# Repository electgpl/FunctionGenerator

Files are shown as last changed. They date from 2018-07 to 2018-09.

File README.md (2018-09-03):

# Generador de Funciones con XR2206 v1.0 

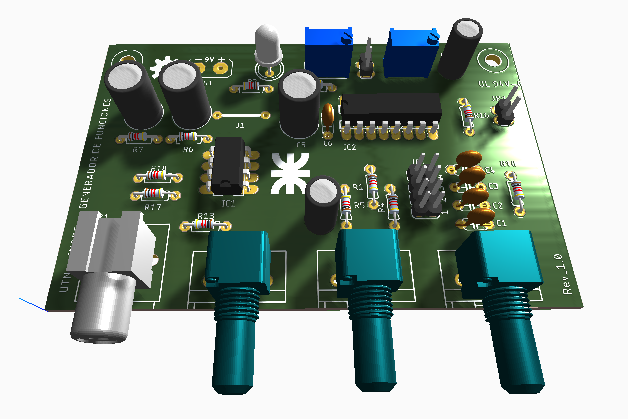
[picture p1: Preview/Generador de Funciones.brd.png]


# Generador de Funciones con XR2206 v2.0 

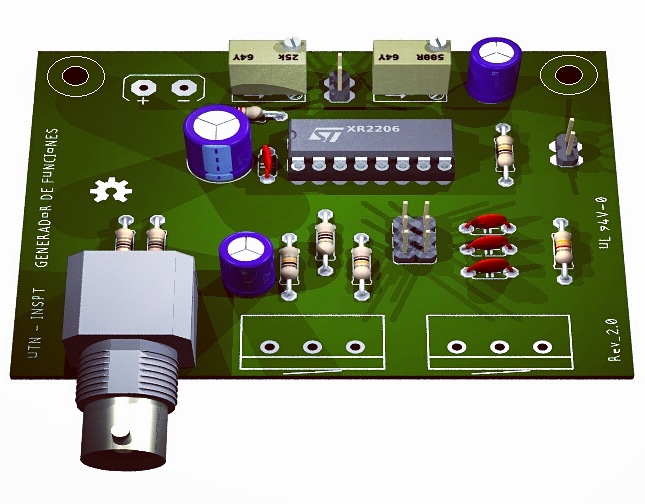
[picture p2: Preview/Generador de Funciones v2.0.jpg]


Este es un Generador de Señales discreto en base a componentes de fácil adquisición para facilitar la producción para ser ensamblado por los estudiantes.

## Controles - v1.0

  - Generador - **XR2206**
  - Preajuste de Simetría
  - Preajuste de Distorsión
  - Ajuste de Amplitud
  - Ajuste de Ganancia
  - Ajuste de Frecuencia
  - Selección de Rango de Frecuencia mediante Jumper o switch (4 rangos)
  - Selección de salida Triangular o Senoidal mediante Jumper o switch
  - Buffer de Salida
  - Salida BNC de 50R
  - Salida Cuadrada para Frecuencímetro y Sincronismo
  
## Controles - v2.0

  - Generador - **XR2206**
  - Preajuste de Simetría
  - Preajuste de Distorsión
  - Ajuste de Amplitud
  - ~~Ajuste de Ganancia~~
  - Ajuste de Frecuencia
  - Selección de Rango de Frecuencia mediante Jumper o switch ~~(4 rangos)~~ (3 rangos)
  - Selección de salida Triangular o Senoidal mediante Jumper o switch
  - ~~Buffer de Salida~~
  - Salida BNC de 50R
  - Salida Cuadrada para Frecuencímetro y Sincronismo

## Alimentacion

> Diseñado para ser alimentado con una única batería de 9V
> en su interior cuenta con una fuente con masa flotante para lograr la simetría en el amplificador operacional (solo para v1.0).
> El amplificador operacional puede ser reemplazado por cualquiera con entrada FET (Se requiere alta impedancia) (solo para v1.0).

### Diseño

> Diseñado con EAGLE, en solo una capa con componentes THT para facilitar
> la integración al alumno, el desarrollo del PCB en el hogar y mantener
> el menor costo posible.

### Pruebas de Señal Seno y Cuadrada

N|Solid

### Pruebas de FFT sobre Seno

N|Solid

Patrocinado
----
N|Solid (https://www.pcbway.es/)

License
----

MIT

**Free Software, Hell Yeah!**

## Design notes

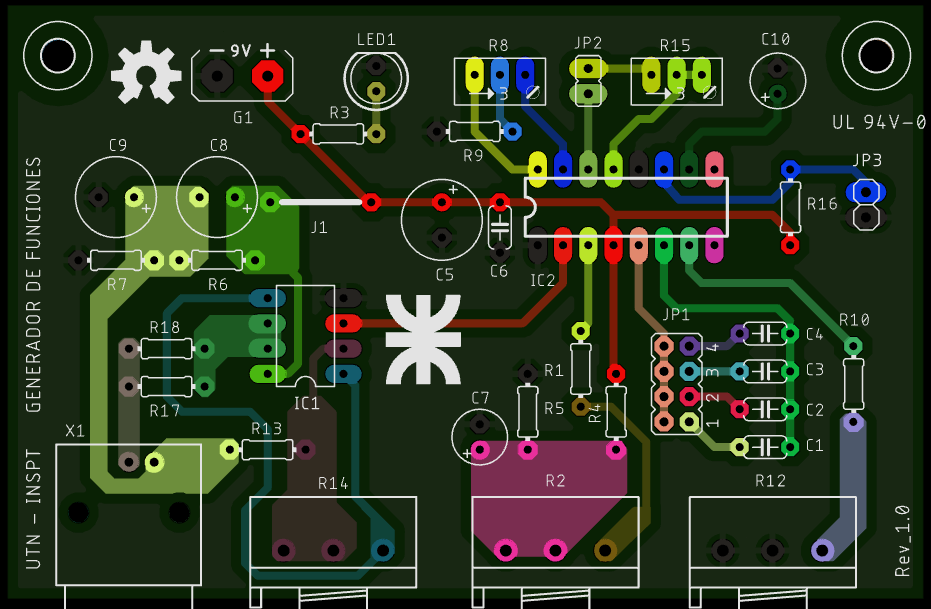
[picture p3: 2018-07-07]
Preview/Generador de Funciones Señales.png

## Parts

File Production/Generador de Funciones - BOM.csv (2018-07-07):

Qty | Value | Device | Package | Parts | Description | MF | MPN | OC_FARNELL | OC_NEWARK | SPICEPREFIX
1 |  | JP1Q | JP1 | JP2 | JUMPER
1 |  | JP4Q | JP4Q | JP1 | JUMPER
1 |  | LED5MM | LED5MM | LED1 | LED
1 |  | PINHD-1X2 | 1X02 | JP3 | PIN HEADER
1 | 1-227161-0 | 1-227161-0 | AMP_227161 | X1 | JACK, RIGHT ANGLE, 50 OHM, PCB, BNC | TYCO ELECTRONICS | 1-227161 | unknown | 33B3200
2 | 100 | R-US_0204/7 | 0204/7 | R17, R18 | RESISTOR, American symbol |  |  |  |  | R
1 | 100k | 3RP/1610N | 3RP/1610N | R12 | 16mm Potentiometer one level
2 | 100n | C-EU050-024X044 | C050-024X044 | C2, C6 | CAPACITOR, European symbol |  |  |  |  | C
1 | 10R | R-US_0204/7 | 0204/7 | R1 | RESISTOR, American symbol |  |  |  |  | R
1 | 10k | 3RP/1610N | 3RP/1610N | R2 | 16mm Potentiometer one level
4 | 10k | R-US_0204/7 | 0204/7 | R4, R5, R13, R16 | RESISTOR, American symbol |  |  |  |  | R
1 | 10n | C-EU050-024X044 | C050-024X044 | C3 | CAPACITOR, European symbol |  |  |  |  | C
1 | 10u | CPOL-EUE2.5-6 | E2,5-6 | C7 | POLARIZED CAPACITOR, European symbol |  |  |  |  | C
4 | 1k | R-US_0204/7 | 0204/7 | R3, R6, R7, R9 | RESISTOR, American symbol |  |  |  |  | R
1 | 1n | C-EU050-024X044 | C050-024X044 | C4 | CAPACITOR, European symbol |  |  |  |  | C
1 | 1u | C-EU050-024X044 | C050-024X044 | C1 | CAPACITOR, European symbol |  |  |  |  | C
1 | 1u | CPOL-EUE2.5-6 | E2,5-6 | C10 | POLARIZED CAPACITOR, European symbol |  |  |  |  | C
2 | 220u | CPOL-EUE3.5-8 | E3,5-8 | C8, C9 | POLARIZED CAPACITOR, European symbol |  |  |  |  | C
1 | 25k | 3RP/1610N | 3RP/1610N | R14 | 16mm Potentiometer one level
1 | 25k | TRIM_EU-RJ9W | RJ9W | R8 | POTENTIOMETER
1 | 3k3 | R-US_0204/7 | 0204/7 | R10 | RESISTOR, American symbol |  |  |  |  | R
1 | 470u | CPOL-EUE3.5-8 | E3,5-8 | C5 | POLARIZED CAPACITOR, European symbol |  |  |  |  | C
1 | 500R | TRIM_EU-RJ9W | RJ9W | R15 | POTENTIOMETER
1 | AB9V | AB9V | AB9V | G1 | 9-V BATTERY CLIP
1 | J10MM | J10MM | 10 | J1 | Bridge
1 | LM358N | LM358N | DIL08 | IC1 | OP AMP also LM158; LM258; LM2904
1 | OSHW-LOGOL | OSHW-LOGOL | OSHW-LOGO-L | U$4 | Open Source Hardware Logo This logo indicates the piece of hardware it is found on incorporates a OSHW license and/or adheres to the definition of open source hardware found here: http://freedomdefined.org/OSHW
1 | UTN_LOGO_0 | UTN_LOGO_0 | UTN_LOGO_0_TOP | U$1
1 | XR2206 | XR2206 | DIL16 | IC2 | XR2206 Monolithic Function Generator

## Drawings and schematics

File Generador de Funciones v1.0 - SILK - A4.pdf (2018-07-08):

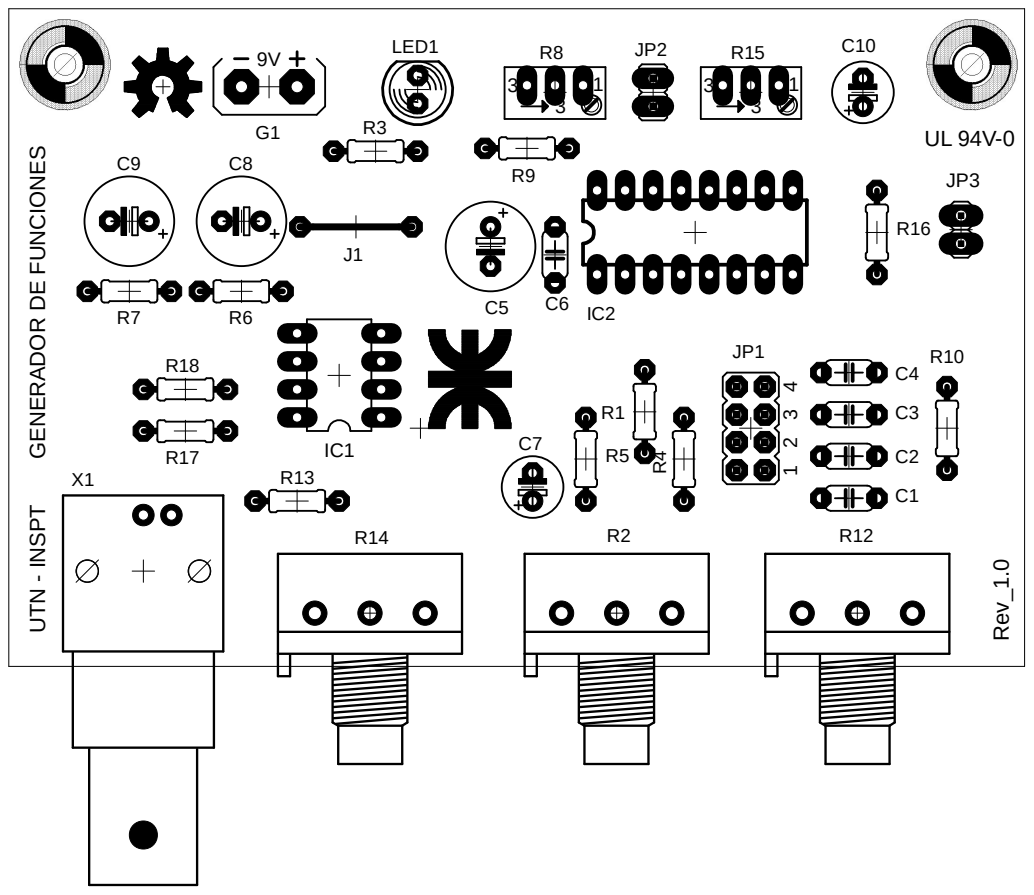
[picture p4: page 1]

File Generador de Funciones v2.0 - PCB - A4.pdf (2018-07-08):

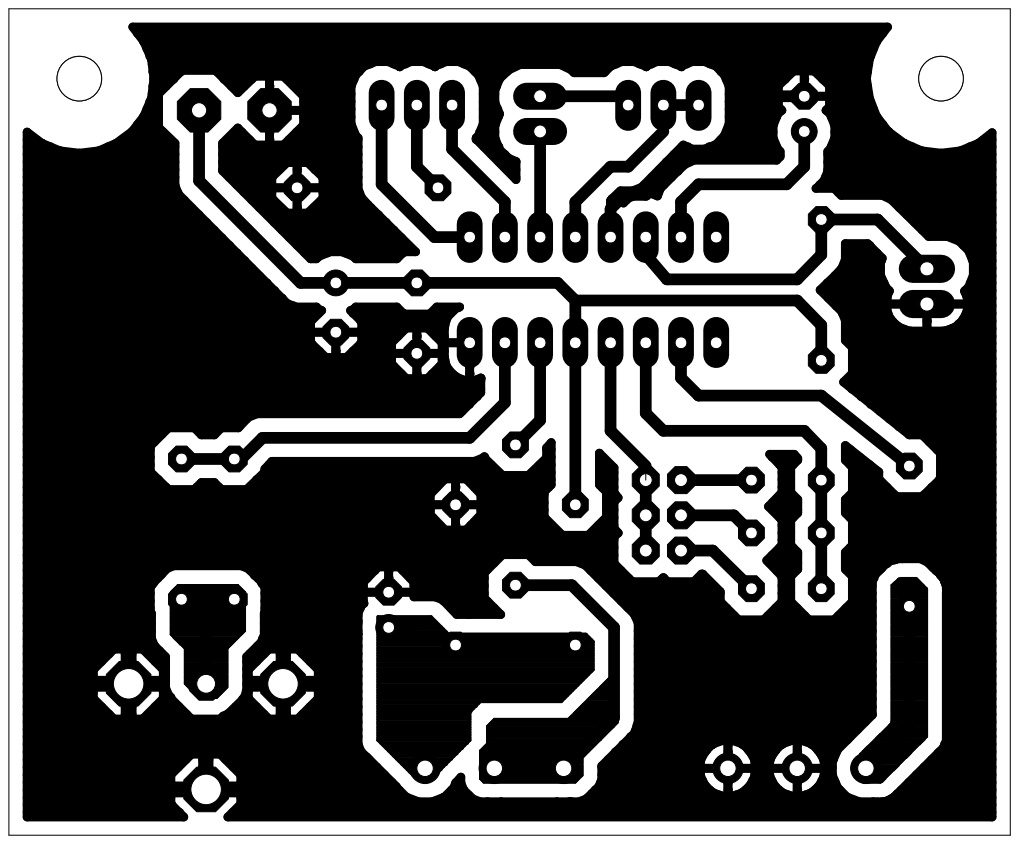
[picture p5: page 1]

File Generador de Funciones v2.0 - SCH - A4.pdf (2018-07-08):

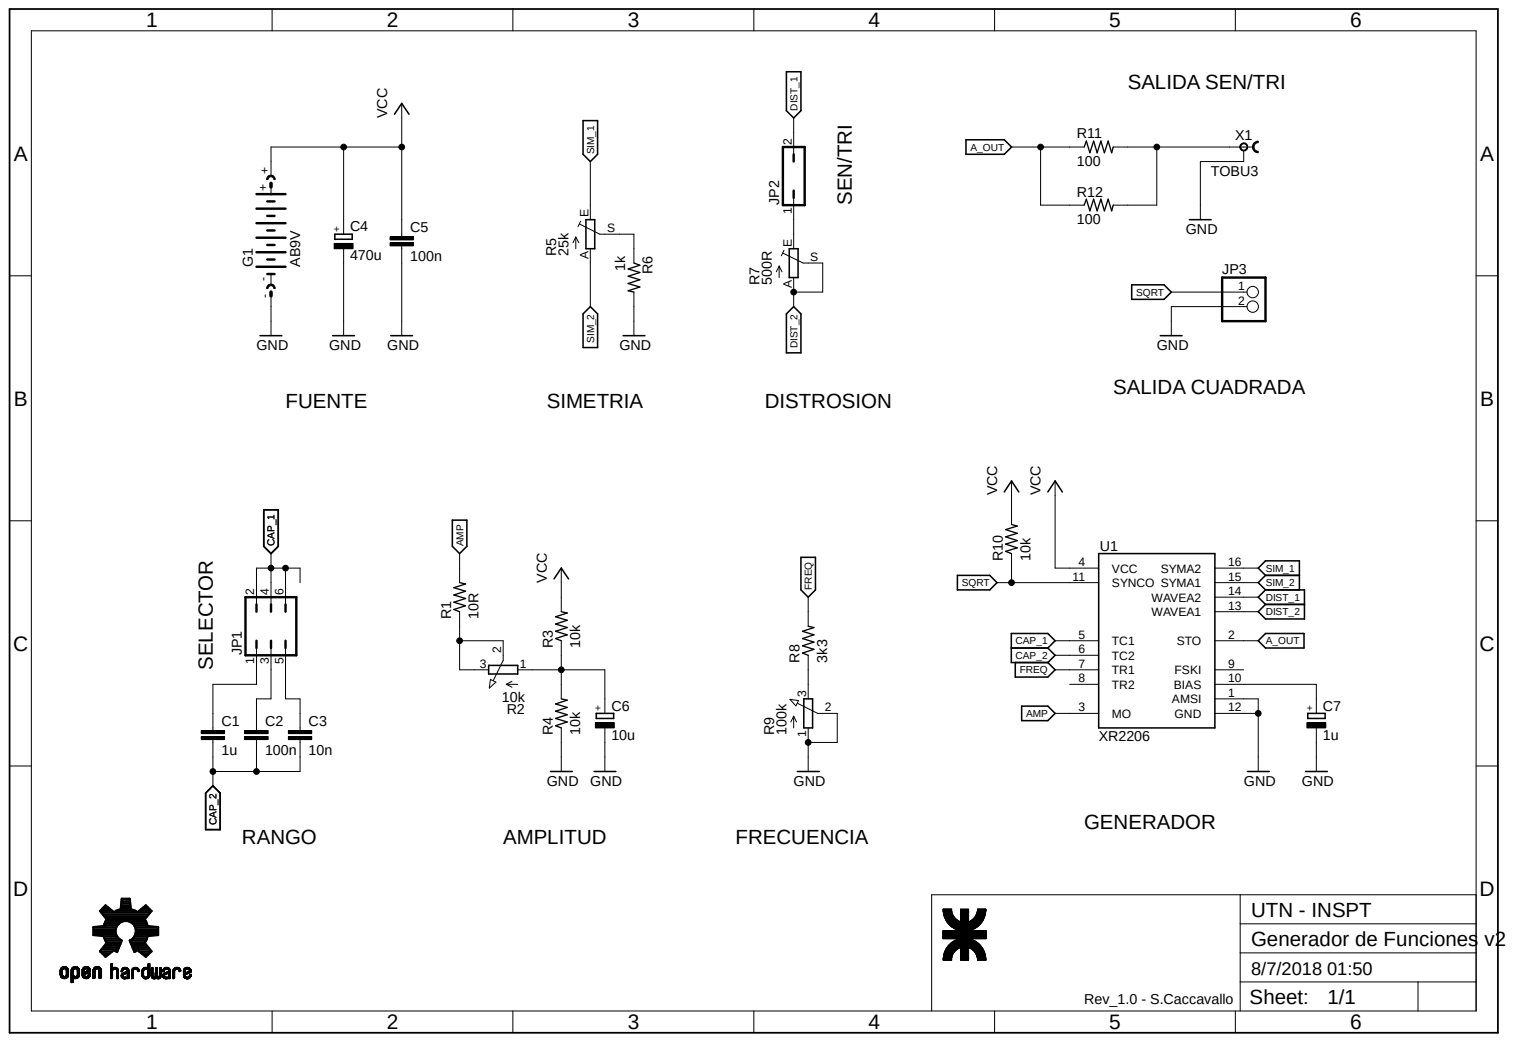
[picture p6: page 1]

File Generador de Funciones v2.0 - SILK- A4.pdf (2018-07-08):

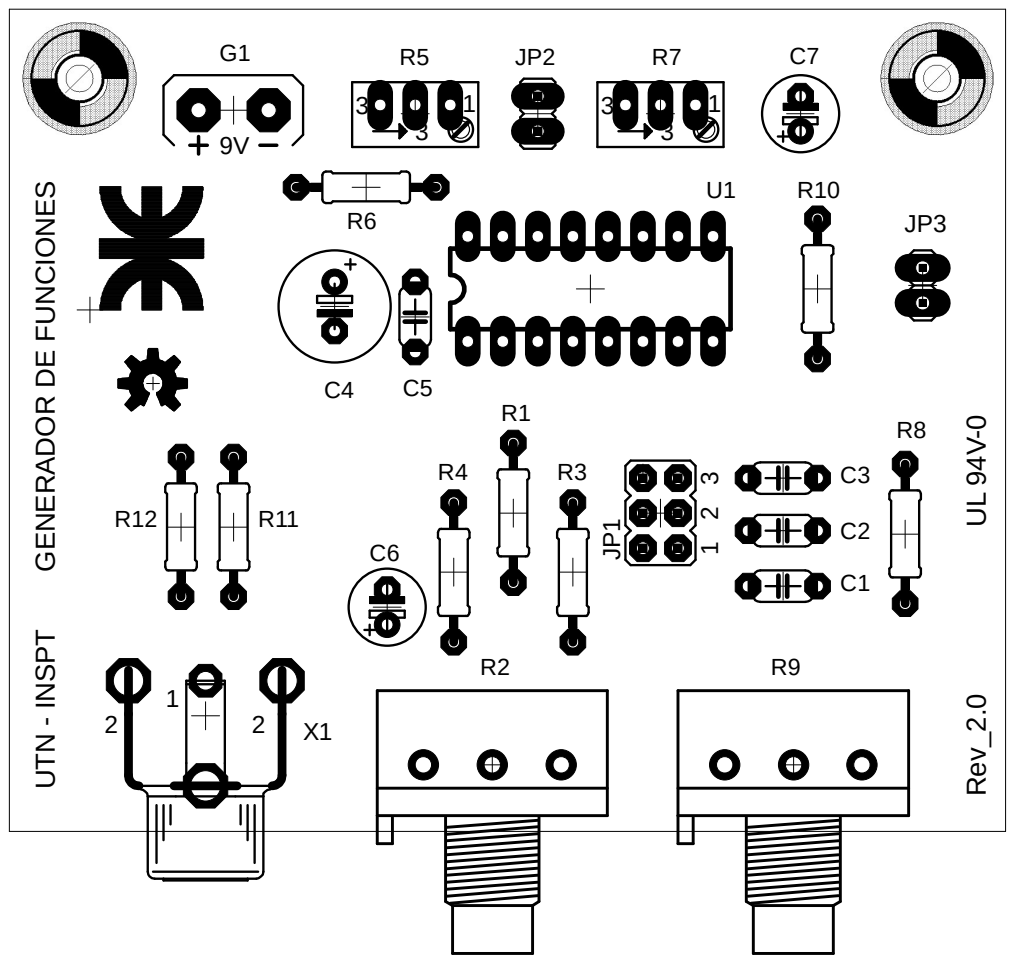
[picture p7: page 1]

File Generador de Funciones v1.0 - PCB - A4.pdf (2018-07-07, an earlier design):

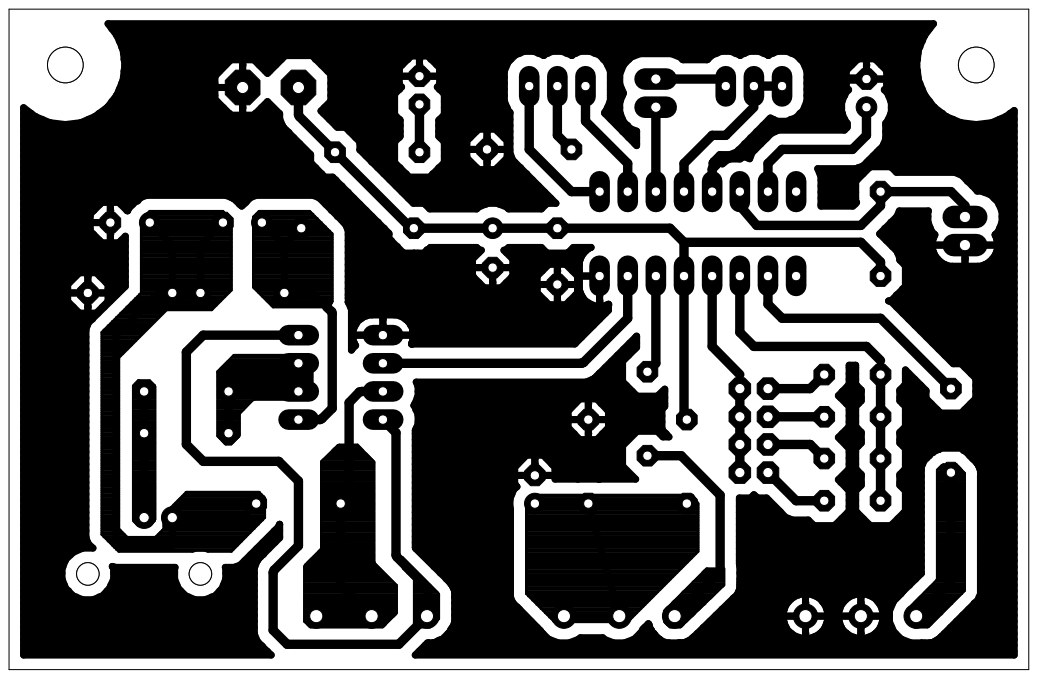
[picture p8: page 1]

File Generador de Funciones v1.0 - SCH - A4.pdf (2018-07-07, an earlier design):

## SALIDA SEN/TRI

A

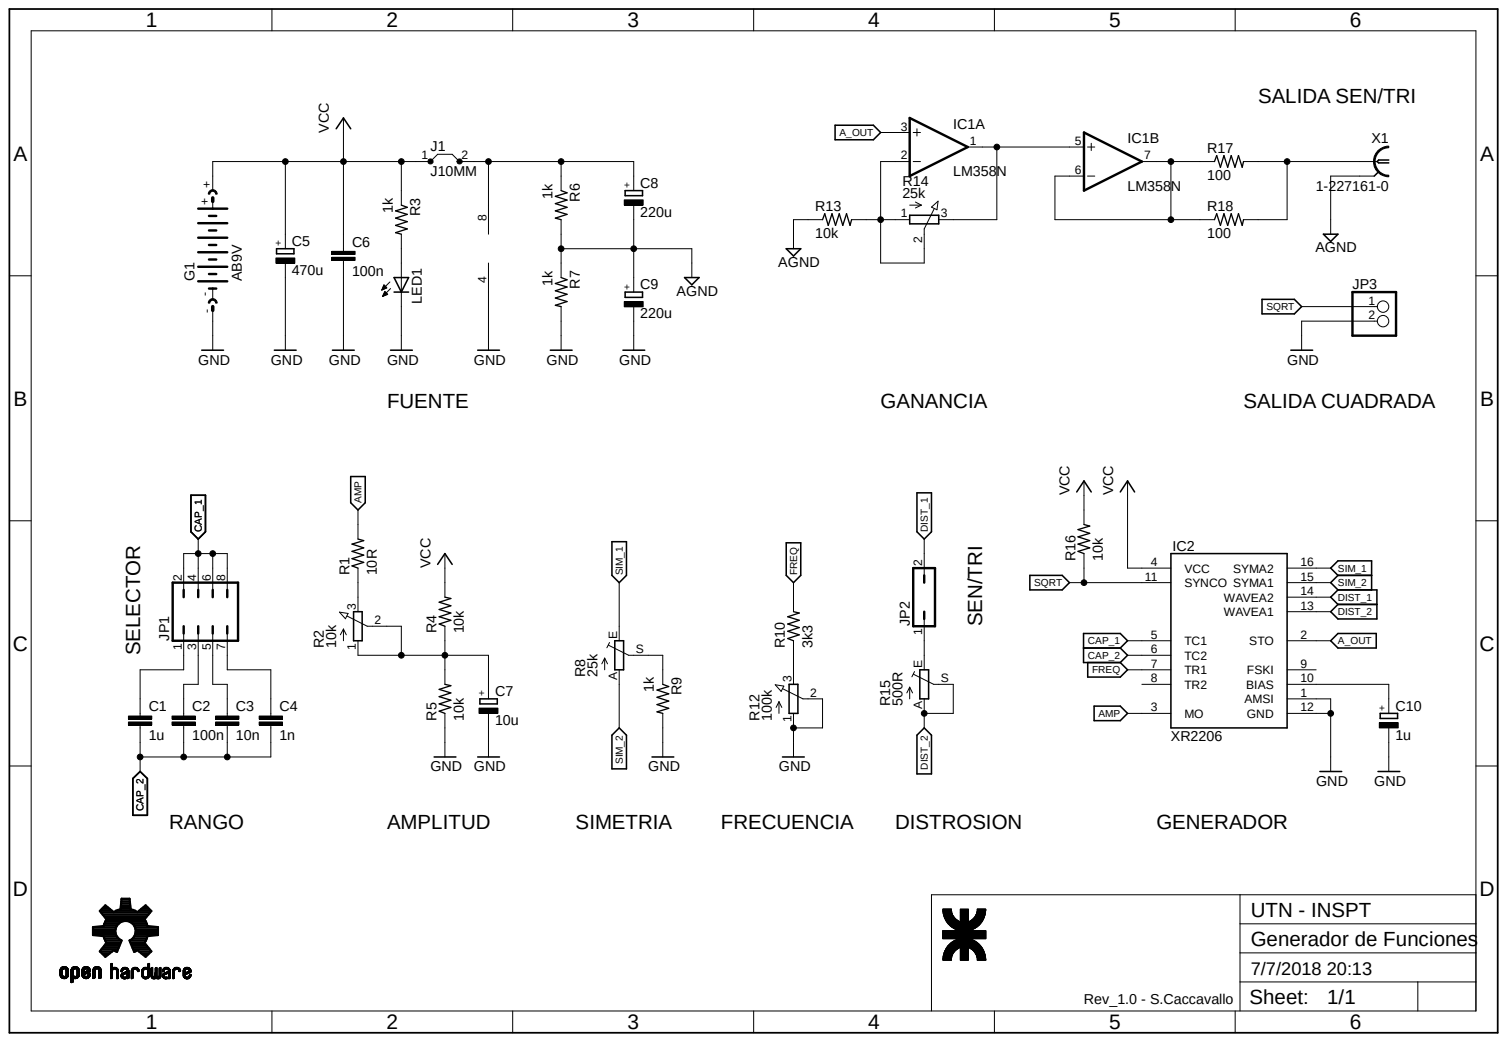
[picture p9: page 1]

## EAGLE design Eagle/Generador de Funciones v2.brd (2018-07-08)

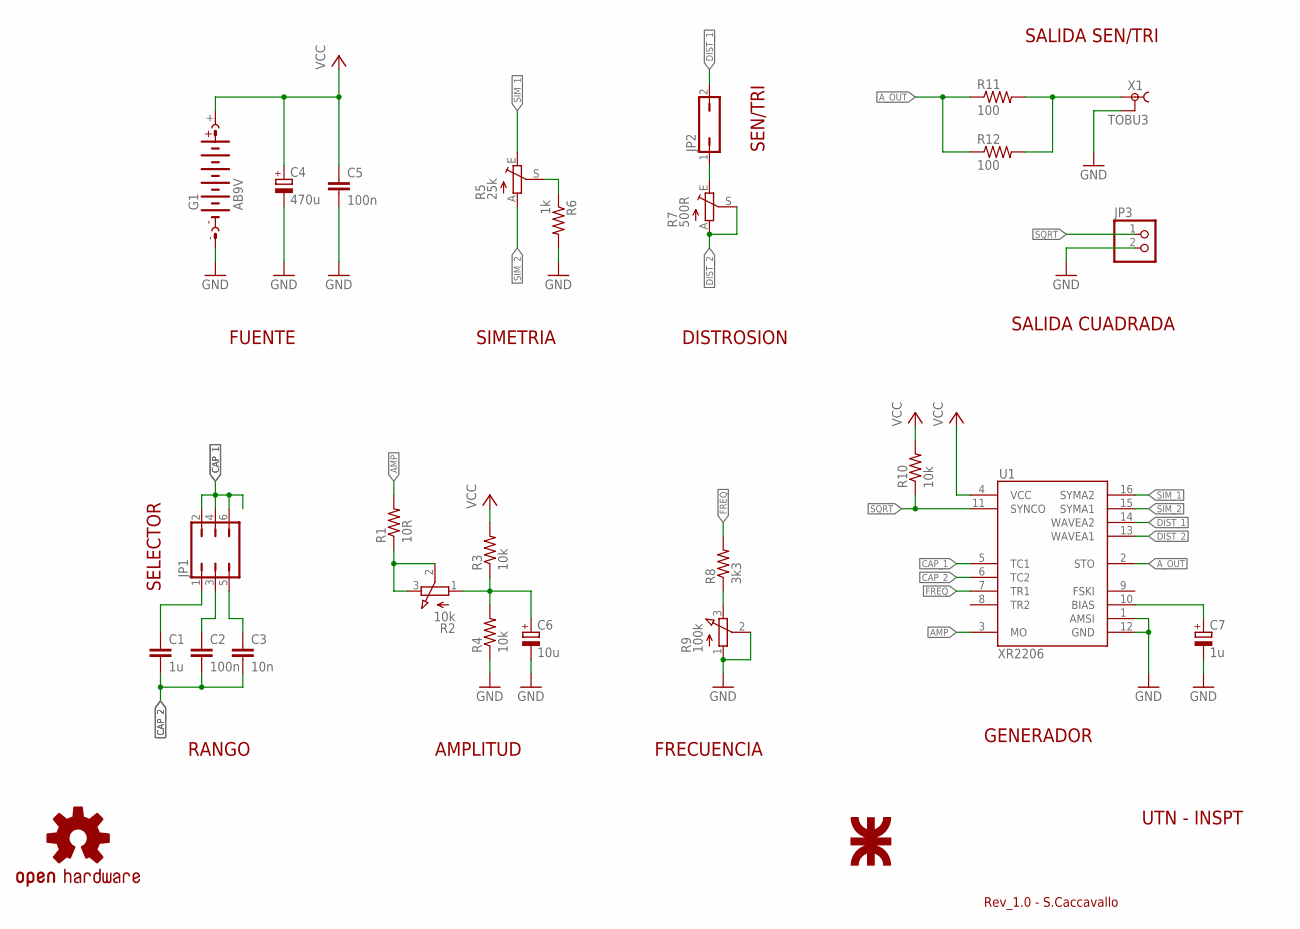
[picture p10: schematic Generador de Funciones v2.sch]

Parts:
C1: 1u; C050-024X044
C2, C5: 100n; C050-024X044
C3: 10n; C050-024X044
C4: 470u; E3,5-8
C6: 10u; E2,5-6
C7: 1u; E2,5-6
G1: AB9V
JP1: JP3Q
JP2: JP1Q; JP1
JP3: PINHD-1X2; 1X02
R1: 10R; 0207/10
R2: 10k; 3RP/1610N
R3, R4, R10: 10k; 0207/10
R5: 25k; RJ9W
R6: 1k; 0207/10
R7: 500R; RJ9W
R8: 3k3; 0207/10
R9: 100k; 3RP/1610N
R11, R12: 100; 0207/10
U1: XR2206; DIL16
U$1: UTN_LOGO_0; UTN_LOGO_0_TOP
U$4: OSHW-LOGOM; OSHW-LOGO-M
X1: TOBU3

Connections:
AMP: R1.2, U1.3 (MO)
A_OUT: R11.1, R12.1, U1.2 (STO)
CAP_1: JP1.2, JP1.4, JP1.6, U1.5 (TC1)
CAP_2: C1.2, C2.2, C3.2, U1.6 (TC2)
DIST_1: JP2.2, U1.14 (WAVEA2)
DIST_2: R7.A, R7.S, U1.13 (WAVEA1)
FREQ: R8.2, U1.7 (TR1)
GND: C4.-, C5.2, C6.-, C7.-, G1.-, JP3.2, R4.1, R6.2, R9.1 (A), R9.2 (S), U1.1 (AMSI), U1.12 (GND), X1.2, X1.2@1 (2), X1.2@2 (2)
unnamed: R1.1, R2.2 (S), R2.3 (E)
unnamed: R8.1, R9.3 (E)
unnamed: C1.1, JP1.1
unnamed: C2.1, JP1.3
unnamed: C7.+, U1.10 (BIAS)
unnamed: R5.S, R6.1
unnamed: C3.1, JP1.5
unnamed: R11.2, R12.2, X1.1
unnamed: JP2.1, R7.E
unnamed: C6.+, R2.1 (A), R3.1, R4.2
SIM_1: R5.E, U1.16 (SYMA2)
SIM_2: R5.A, U1.15 (SYMA1)
SQRT: JP3.1, R10.1, U1.11 (SYNCO)
VCC: C4.+, C5.1, G1.+, R3.2, R10.2, U1.4 (VCC)

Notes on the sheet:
RANGO
AMPLITUD
FRECUENCIA
SIMETRIA
DISTROSION
FUENTE
SELECTOR
SEN/TRI
UTN - INSPT
SALIDA SEN/TRI
GENERADOR
SALIDA CUADRADA
Rev_1.0 - S.Caccavallo

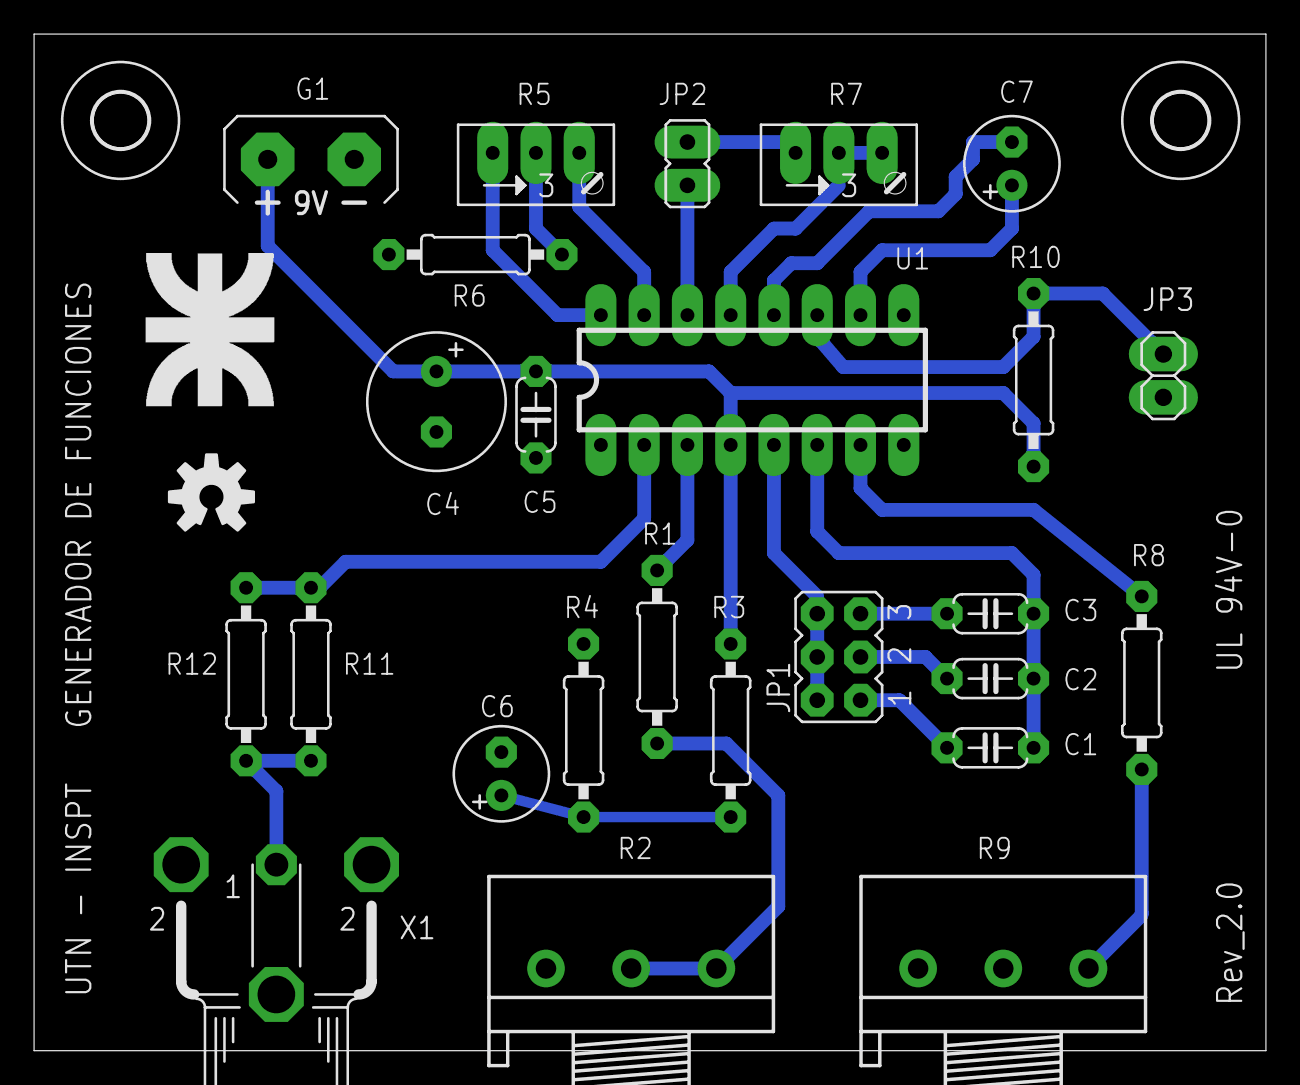
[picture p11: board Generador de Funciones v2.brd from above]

Board: 2 copper layers, 72.3 x 59.7 mm, 29 parts (0 on the bottom side), 22 nets.

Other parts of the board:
U$2, U$3: 3,2

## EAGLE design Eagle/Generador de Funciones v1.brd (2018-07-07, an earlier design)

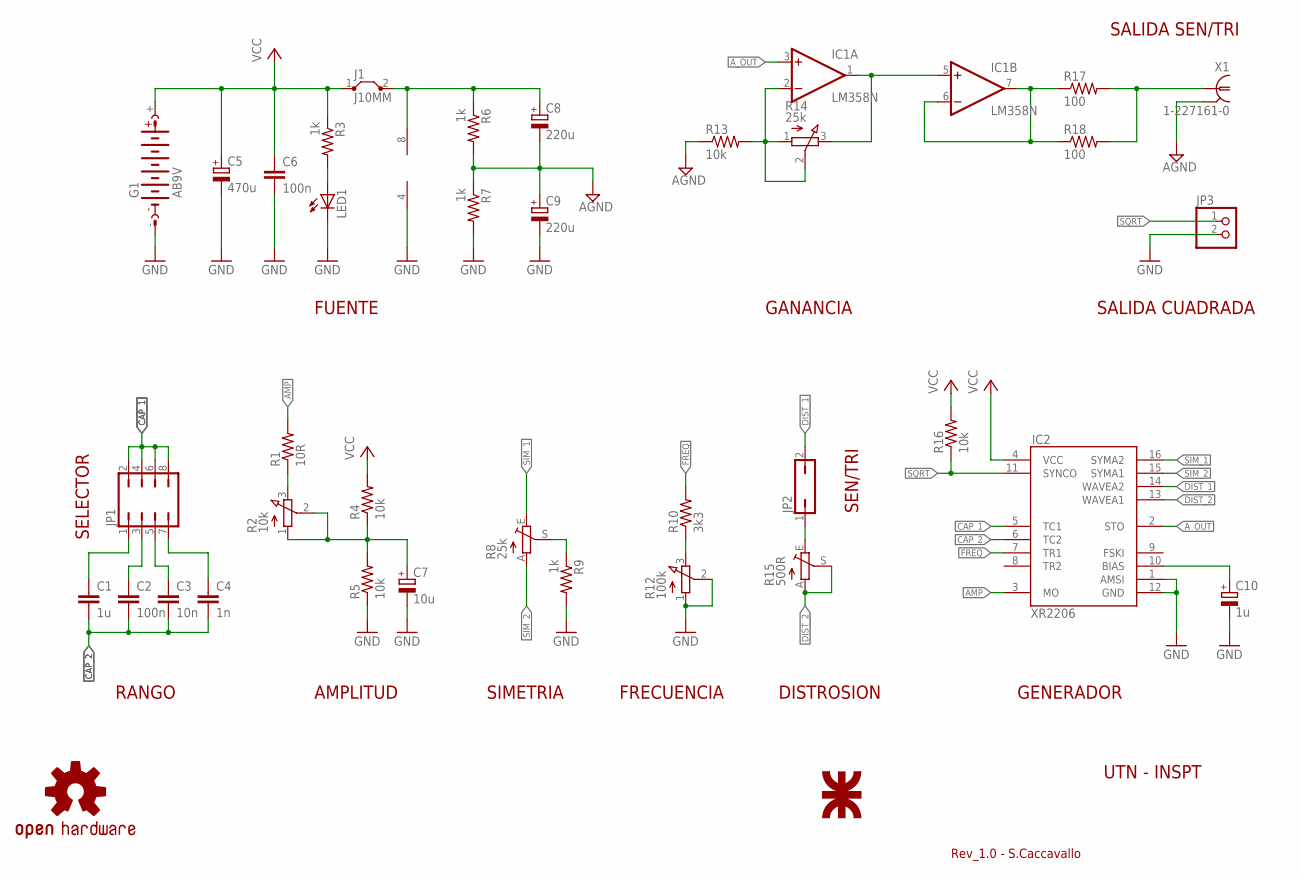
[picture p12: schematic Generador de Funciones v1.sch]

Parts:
C1: 1u; C050-024X044
C2, C6: 100n; C050-024X044
C3: 10n; C050-024X044
C4: 1n; C050-024X044
C5: 470u; E3,5-8
C7: 10u; E2,5-6
C8, C9: 220u; E3,5-8
C10: 1u; E2,5-6
G1: AB9V
IC1: LM358N; DIL08
IC2: XR2206; DIL16
J1: J10MM; 10
JP1: JP4Q
JP2: JP1Q; JP1
JP3: PINHD-1X2; 1X02
LED1: LED5MM
R1: 10R; 0204/7
R2: 10k; 3RP/1610N
R3, R6, R7, R9: 1k; 0204/7
R4, R5, R13, R16: 10k; 0204/7
R8: 25k; RJ9W
R10: 3k3; 0204/7
R12: 100k; 3RP/1610N
R14: 25k; 3RP/1610N
R15: 500R; RJ9W
R17, R18: 100; 0204/7
U$1: UTN_LOGO_0; UTN_LOGO_0_TOP
U$4: OSHW-LOGOL; OSHW-LOGO-L
X1: 1-227161-0; AMP_227161

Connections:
AGND: C8.-, C9.+, R6.2, R7.1, R13.1, X1.2
AMP: IC2.3 (MO), R1.2
A_OUT: IC1.3 (+IN), IC2.2 (STO)
CAP_1: IC2.5 (TC1), JP1.2, JP1.4, JP1.6, JP1.8
CAP_2: C1.2, C2.2, C3.2, C4.2, IC2.6 (TC2)
DIST_1: IC2.14 (WAVEA2), JP2.2
DIST_2: IC2.13 (WAVEA1), R15.A, R15.S
FREQ: IC2.7 (TR1), R10.2
GND: C5.-, C6.2, C7.-, C9.-, C10.-, G1.-, IC1.4 (V-), IC2.1 (AMSI), IC2.12 (GND), JP3.2, LED1.K (C), R5.1, R7.2, R9.2, R12.1 (A), R12.2 (S)
unnamed: IC1.2 (-IN), R13.2, R14.1 (A), R14.2 (S)
unnamed: R1.1, R2.3 (E)
unnamed: R10.1, R12.3 (E)
unnamed: C1.1, JP1.1
unnamed: C2.1, JP1.3
unnamed: C10.+, IC2.10 (BIAS)
unnamed: R8.S, R9.1
unnamed: C3.1, JP1.5
unnamed: C4.1, JP1.7
unnamed: R17.2, R18.2, X1.1
unnamed: LED1.A, R3.2
unnamed: JP2.1, R15.E
unnamed: C7.+, R2.1 (A), R2.2 (S), R4.1, R5.2
unnamed: IC1.1 (OUT), IC1.5 (+IN), R14.3 (E)
unnamed: IC1.6 (-IN), IC1.7 (OUT), R17.1, R18.1
unnamed: C8.+, IC1.8 (V+), J1.2, R6.1
SIM_1: IC2.16 (SYMA2), R8.E
SIM_2: IC2.15 (SYMA1), R8.A
SQRT: IC2.11 (SYNCO), JP3.1, R16.1
VCC: C5.+, C6.1, G1.+, IC2.4 (VCC), J1.1, R3.1, R4.2, R16.2

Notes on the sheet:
RANGO
AMPLITUD
FRECUENCIA
SIMETRIA
DISTROSION
FUENTE
SELECTOR
SEN/TRI
UTN - INSPT
SALIDA SEN/TRI
GENERADOR
SALIDA CUADRADA
GANANCIA
Rev_1.0 - S.Caccavallo

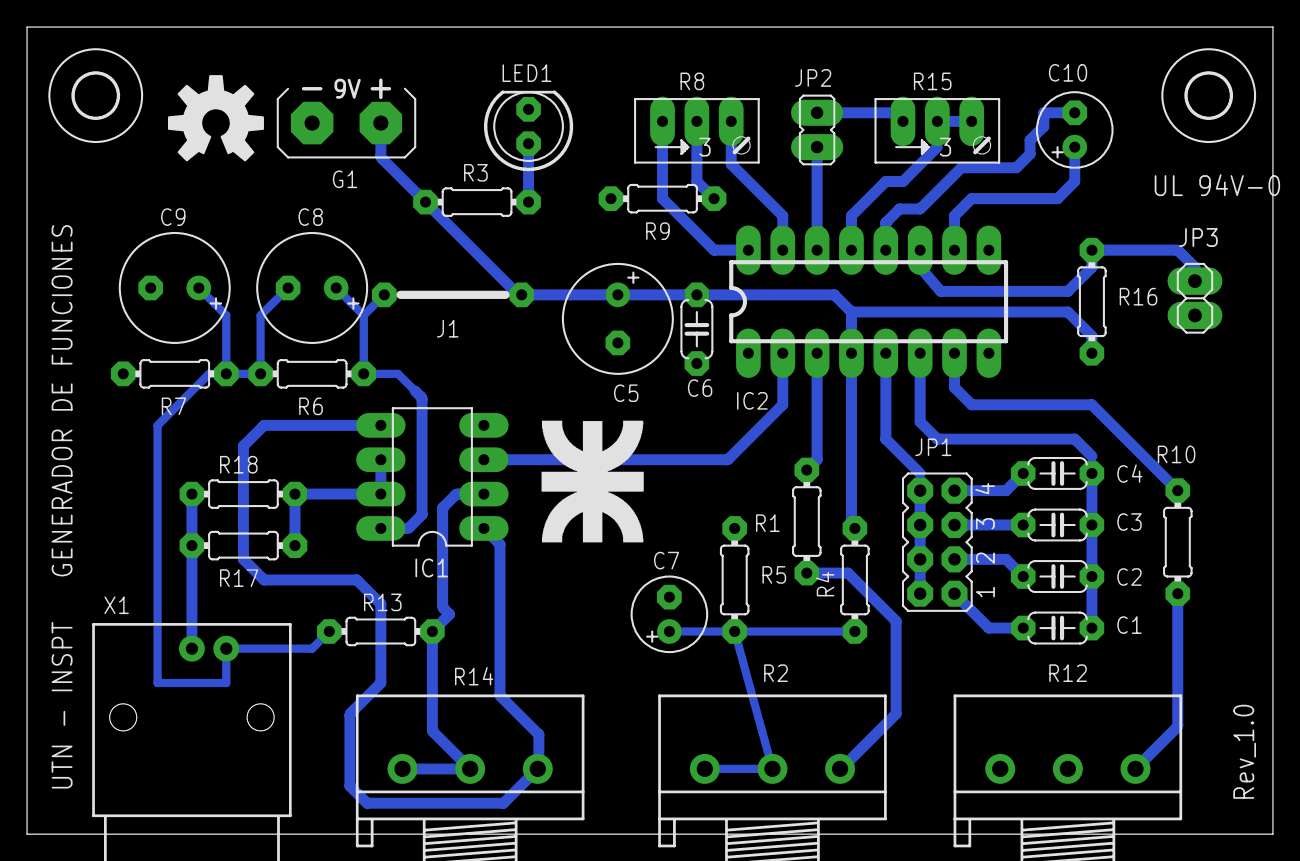
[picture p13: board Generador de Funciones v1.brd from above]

Board: 2 copper layers, 92.1 x 59.7 mm, 40 parts (0 on the bottom side), 29 nets.

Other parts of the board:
U$2, U$3: 3,2

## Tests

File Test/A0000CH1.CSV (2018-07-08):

Memory Length | 4000
Trigger Level | 0.000E+00
Source | CH1
Probe | 1X
Vertical Units | V
Vertical Scale | 5.000E-01
Vertical Position | 4.800E-01
Horizontal Units | s
Horizontal Scale | 1.000E-03
Horizontal Position | 0.000E+00
Horizontal Mode | Main
Sampling Period | 4.000E-06
Firmware | V1.24
Time
Mode | Fast
Waveform Data
10
10
-5
-5
-6
-7
-7
-7
-7
-8
-7
-8
-8
-8
-8
-9
-9
-10
-9
-10
-10
-10
-11
-11
-11
-11
-11
-11
-12
-12
-12
-13
-13
-13
-14
-14
-13
-14
-15
-15
-15
-16
-15
-15
-15
-16
-17
-17
-17
-16
-16
-17
-18
-17
-17
-18
-18
-18
-18
-18
-18
-19
-19
-18
-19
-20
-20
-19
-20
-20
-20
-21
-20
-20
-20
-21
-22
-21
-21
-21
-21
-21
-21
-20
-21
-21
-21
-22
-21
-22
-23
-22
-21
-21
-22
-22
-22
-22
-22
-22
-23
-24
-23
-22
-22
-23
-22
-22
-23
-23
-22
-22
-22
-21
-22
-23
-22
-22
-23
-23
-23
-23
-23
-23
-22
-23
-23
-23
-23
-23
-23
-22
-23
-23
-23
-24
-23
-23
-23
-23
-23
-23
-22
-23
-23
-22
-23
-22
-22
-22
-23
-24
-23
-22
-23
-23
-23
-23
-23
-23
-22
-23
-23
-21
-22
-23
-22
-20
-22
-22
-22
-22
-22
-22
-21
-21
-23
-22
-21
-22
-21
-20
-21
-21
-21
-21
-20
-20
-19
-20
-21
-20
-19
-19
-19
-19
-20
-19
-19
-18
-17
-18
-18
-17
-17
-17
-17
-17
-16
-17
-16
-15
-16
-14
-15
-15
-15
-15
-14
-14
-14
-14
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

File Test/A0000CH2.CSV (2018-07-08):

Memory Length | 4000
Trigger Level | 0.000E+00
Source | CH2
Probe | 1X
Vertical Units | V
Vertical Scale | 5.000E+00
Vertical Position | -9.800E+00
Horizontal Units | s
Horizontal Scale | 1.000E-03
Horizontal Position | 0.000E+00
Horizontal Mode | Main
Sampling Period | 4.000E-06
Firmware | V1.24
Time
Mode | Fast
Waveform Data
-24
-24
-24
-24
-24
-24
-24
-24
-24
-24
-24
-24
-24
-24
-24
-24
-24
-25
-23
-25
-24
-24
-24
-24
-24
-24
-24
-24
-25
-24
-24
-24
-24
-24
-24
-24
-25
-24
-24
-24
-24
-24
-24
-24
-24
-24
-25
-24
-24
-24
-24
-24
-24
-24
-24
-24
-24
-23
-24
-24
-25
-24
-24
-24
-24
-24
-24
-24
-24
-24
-24
-24
-24
-24
-24
-24
-23
-24
-24
-24
-24
-24
-24
-24
-24
-24
-24
-24
-24
-24
-24
-24
-24
-24
-24
-24
-24
-24
-24
-24
-24
-24
-24
-24
-24
-24
-24
-24
-24
-24
-24
-23
-24
-24
-24
-24
-24
-24
-24
-25
-24
-24
-25
-24
-24
-24
-24
-24
-24
-24
-24
-24
-24
-24
-24
-24
-11
9
17
19
20
20
20
20
20
21
20
20
20
20
20
21
20
21
20
20
21
21
20
21
21
20
20
21
20
20
20
20
20
20
20
20
21
20
20
21
20
20
20
20
20
20
21
20
20
20
20
20
21
20
21
20
20
21
20
20
21
20
20
20
20
20
20
20
20
20
20
21
20
20
20
20
20
20
20
20
20
20
21
20
20
21
20
20
20
20
20
21
20
20
20
20
20
20
20
21
21
20
20
21
20
20
20
20
20
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

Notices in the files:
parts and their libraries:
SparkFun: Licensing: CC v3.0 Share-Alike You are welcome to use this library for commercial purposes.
